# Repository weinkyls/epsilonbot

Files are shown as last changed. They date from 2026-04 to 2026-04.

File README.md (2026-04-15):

# The Delta Bot

### What is the Delta Bot?
The Delta Bot is an open-source DIY robot AI platform that uses Radxa's single board computer, the [Rock 5B](https://radxa.com/products/rock5/5b/), a simple [camera module](https://www.raspberrypi.com/products/camera-module-v2/), Parallax's [Continuous Rotation Servo Motors](https://www.parallax.com/product/parallax-continuous-rotation-servo-factory-centered/), and the [RPLIDAR A1](https://www.slamtec.com/en/lidar/a1), a LIDAR camera by Slamtec.

<p align="center">
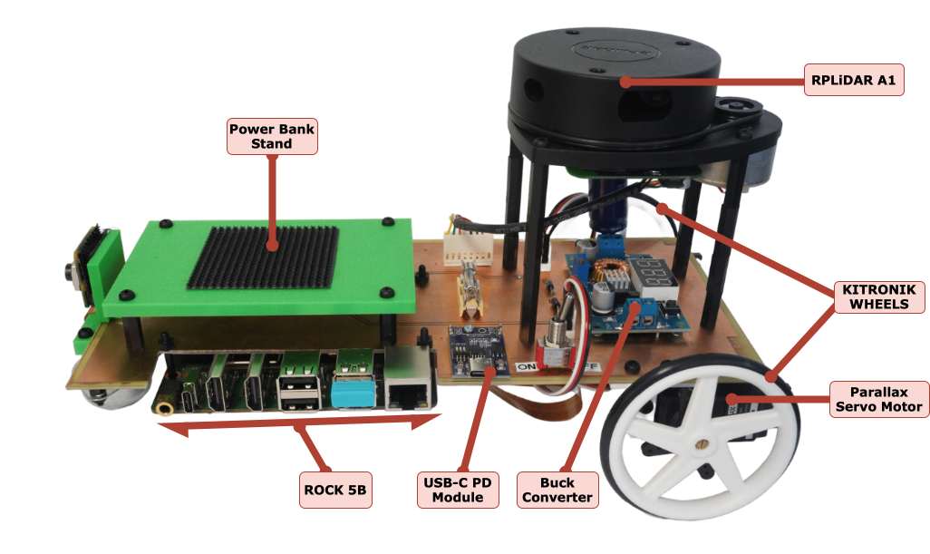
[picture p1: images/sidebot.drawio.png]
Side View
  
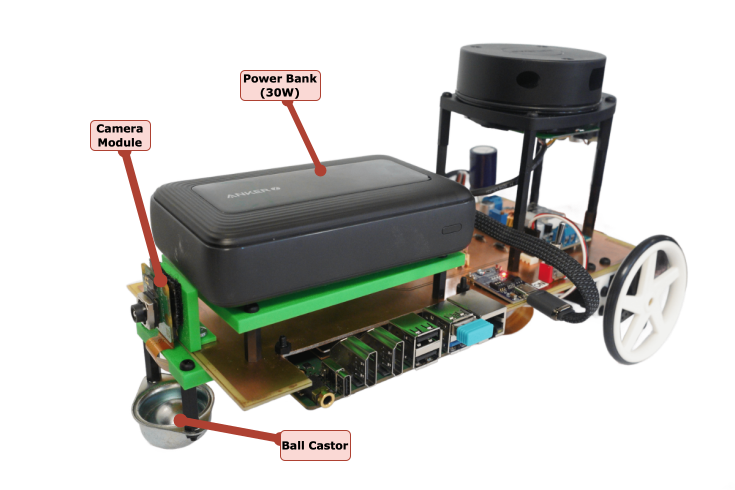
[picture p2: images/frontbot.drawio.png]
Front View
  
</p>

### Purpose & Vision

<p align="center">
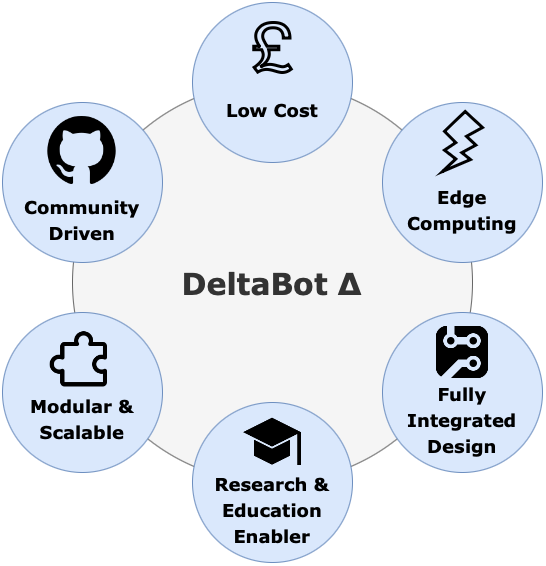
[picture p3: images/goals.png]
Goals
  
</p>

### What can it do?

- 360 Degree 2D LiDAR Scans
- Precise Servo Movement 
- 1080p Video Capture
- Can be configured for Line Following, SLAM, Obstacle Detection, and more!

### Additional Mechanical Parts
Additional Mechanical Parts were designed in CAD and can be accessed [here](additional_files/deltabot.f3z).
These were used to secure the external components onto the Single PCB Chassis:
<p align="center">
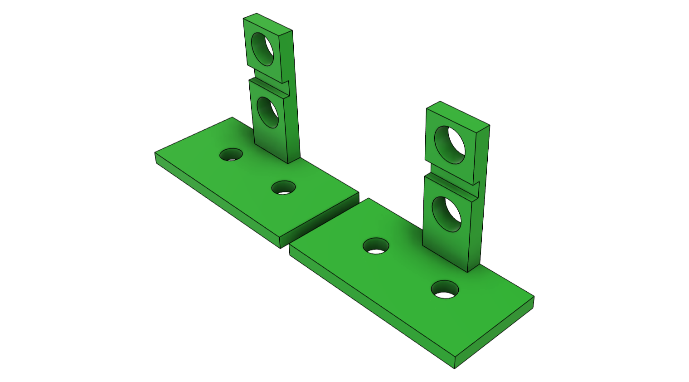
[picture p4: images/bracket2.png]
  
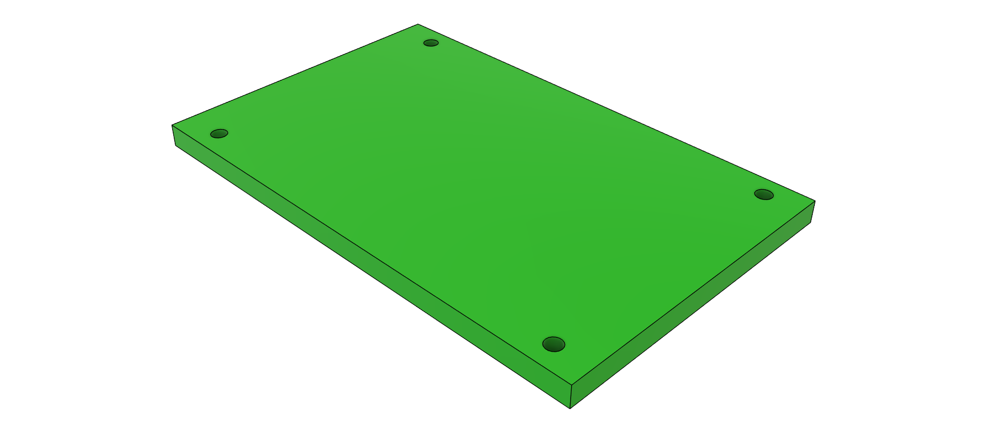
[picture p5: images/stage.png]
  
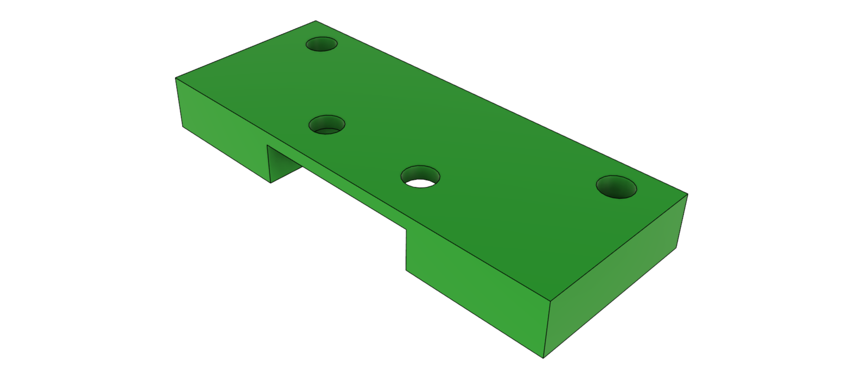
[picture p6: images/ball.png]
  
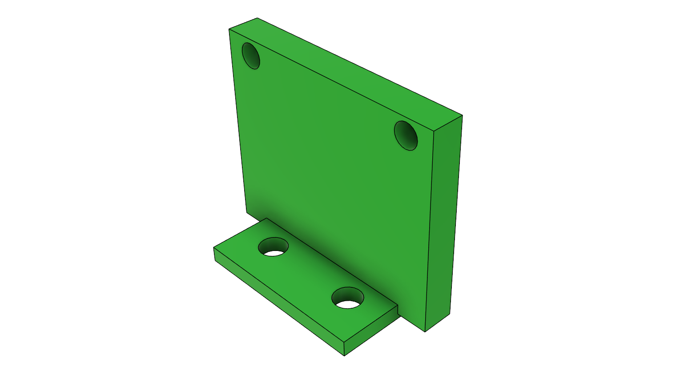
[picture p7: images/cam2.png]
  
</p>

## Credits
- Saleh AlMulla - 2721704A@student.gla.ac.uk
- Bernd Porr -  bernd.porr@glasgow.ac.uk

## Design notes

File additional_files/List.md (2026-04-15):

### Ordered:

- USB C PD - [CRGANGZY PD/QC/AFC Type-C Fast Charge Trigger Polling Detector PD2.0 PD3.0 To DC Fast Charge Trigger Board Voltage Output](https://www.amazon.co.uk/CRGANGZY-Trigger-Polling-Detector-Voltage/dp/B0DBJ388K9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) 
- DC-DC BUCK CONVERTER - [DollaTek Small DC Buck Voltage Converter Step Down Voltage Regulator Module Board 4-38V to 1.25-36V 5V/12V Adjustable Output Voltage Stabilizer Transformer](https://www.amazon.co.uk/dp/B07DK6WN63?ref=ppx_yo2ov_dt_b_fed_asin_title)
- M.2 NVME 256GB - [Silicon Power PCIe M.2 NVMe SSD 256GB Gen3x4 R/W up to 2, 100/1, 200MB/s Internal SSD](https://www.amazon.co.uk/dp/B07ZH6QR8Q?ref=ppx_yo2ov_dt_b_fed_asin_title&th=1)
- RADXA ROCK5B - [Radxa ROCK 5 Model B 8GB Single Board Computer, 249-3159 \(Board Computer\)](https://www.amazon.co.uk/Single-Computer-Rockchip-Cortex-A76-Rock/dp/B0BRL4PCG7/) 
- x2 Parallax Continuous Rotation Servo Motors - [900-00008 PARALLAX, SERVO- CONTINUOUS ROTATION-S3 SERVO](https://uk.farnell.com/parallax/900-00008/servo-continuous-rotation-s3-servo/dp/2819351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) 
- x2 Kitronic Wheels - [2593-SV KITRONIK, Wheel Kit, White, 5 Spoke, ABS, Rotation Servo Motors | Newark Electronics](https://www.newark.com/kitronik/2593-sv/wheels-white-rotation-servo-motor/dp/30AK0833)
- RPLIDAR A1 - [DFR0315 DFROBOT, Development Kit, 2D Laser Scanner, 360°, 5.5Hz, 12m range](https://uk.farnell.com/dfrobot/dfr0315/dev-kit-360-deg-laser-scanner/dp/3517894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)
- RPi Camera Module 3 - [Raspberry Pi Camera Module 3](https://thepihut.com/products/raspberry-pi-camera-module-3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)
- Anker Zolo PowerBank - [Anker Zolo Power Bank, 20,000mAh 30W](https://www.amazon.co.uk/dp/B0CZ9LH53B?ref=ppx_yo2ov_dt_b_fed_asin_title&th=1)

### 3D-Printed:
- x2 Servo Mounting Brackets
- Camera Mounting Bracket
- Castor Ball Mounting Bracket
- Power Bank Stage

### Standard Components:
- SPDT Toggle Switch
- F3.15L250V fuse
- x2 1N4007 Diodes
- Fuse Holder & 3A Fuse
- 40 pin 2x20 GPIO Stackable Header 2.54mm
- x2 1x3 Pin Header 2.54mm
- 1x7 Pin Header 2.54mm

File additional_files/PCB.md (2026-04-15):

# DeltaBot PCB Overview

The DeltaBot PCB was designed in **KiCad** with a double-sided layer layout. The design integrates key subsystems including the **Radxa ROCK 5B**, LiDAR sensor, camera module, and servo motors.

<p align="center">
  
</p>

---

## Power System
- Powered via **USB-C Power Delivery (PD)** module at **9V**, stepped down to **5V** using a **DC-DC buck converter**
- A **3.15A fuse** protects against overcurrent
- An **SPDT switch** provides manual ON/OFF control
- A **2200 µF capacitor** suppresses 5V rail ripple for improved voltage stability
- **1 uF** blocking capacitors between each POWER & GND

The following summarizes the power distribution architecture:

<p align="center">
  
</p>

_Note: Current draw listed is based on peak operational requirements._

---

## PCB Layout (Front & Back Layers)

<p align="center">
  
</p>
<p align="center">
  
</p>

---

## ROCK 5B GPIO Pin Assignments

| Function | GPIO Pin(s) | Description |
|---|---|---|
| +5V Power | 2, 4 | Supplies power to board |
| GND | Multiple | Ground reference |
| UART_TX | 8 | TX to LiDAR's RX |
| UART_RX | 10 | RX from LiDAR's TX |
| MOTO_CTRL | 18 | PWM for LiDAR motor |
| PWM_L | 32 | PWM control for left servo |
| PWM_R | 33 | PWM control for right servo |

To change or add to the layout, check [here](https://wiki.radxa.com/Rock5/hardware/5b/gpio) for the rock's gpio connections.

---

## Connectors

- **J2 (LiDAR)**: 7-pin Molex  
  - UART (TX/RX), PWM for motor control, 5V & 8.34V power lines
  - There is a useful image on the LiDAR wiring in the read.me of [this repository](https://github.com/berndporr/rplidar_rpi).
- **J3 / J4 (Servo Motors)**: 3-pin headers  
  - 5V, GND, PWM (Left/Right)

---

## Files

- [Full Schematic](schematic_files/DeltaBot.kicad_sch)
- [PCB Design](schematic_files/DeltaBot.kicad_pcb)
- [PCB Footprints](schematic_files/deltabot.pretty.zip)
- [Rock 5B KiCAD Symbol](schematic_files/deltabot.lib.kicad_sym)
  
---

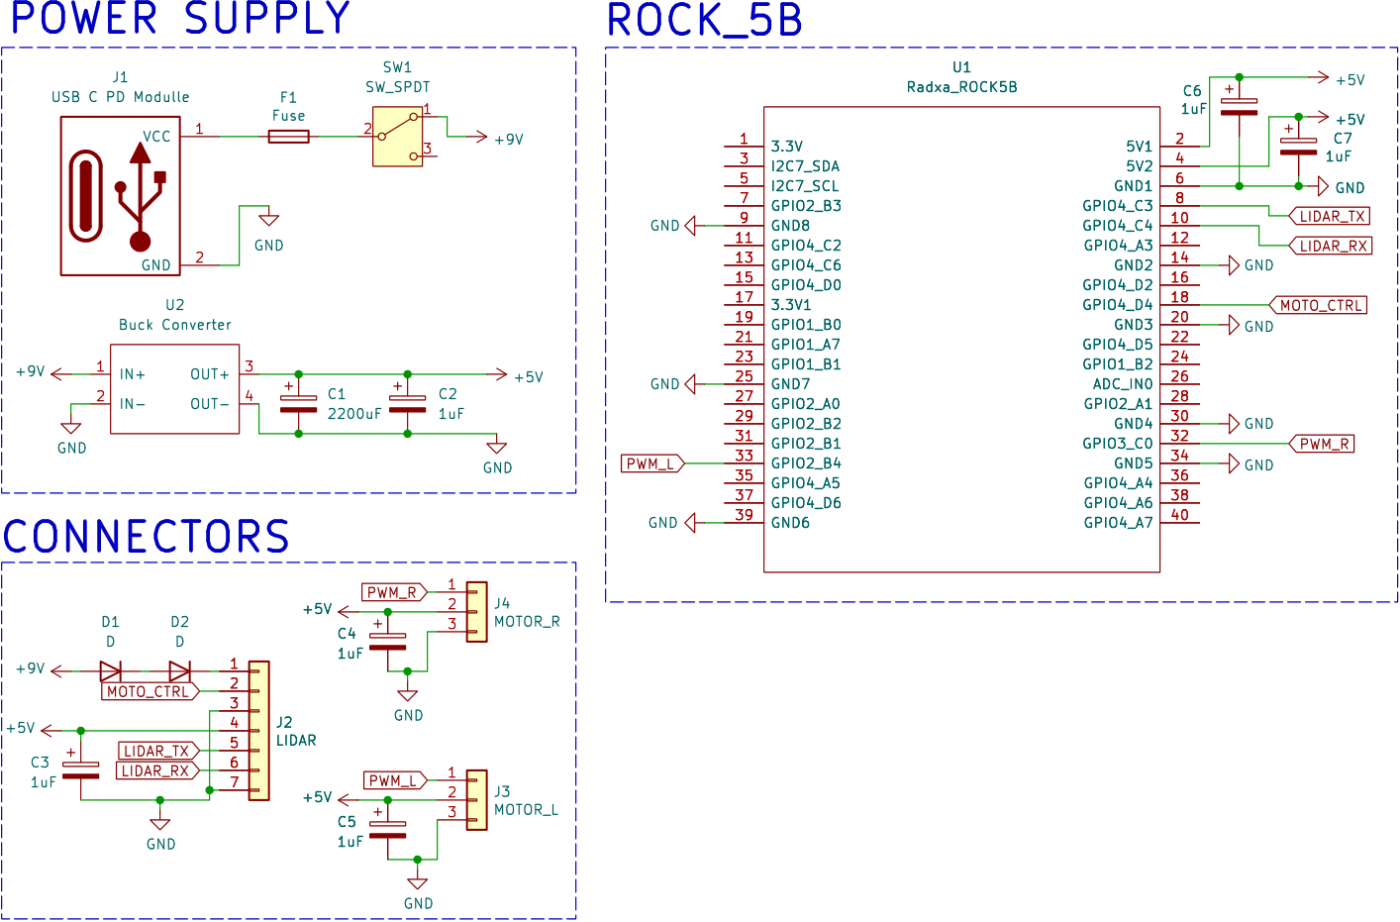
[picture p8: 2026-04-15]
images/schematic.png

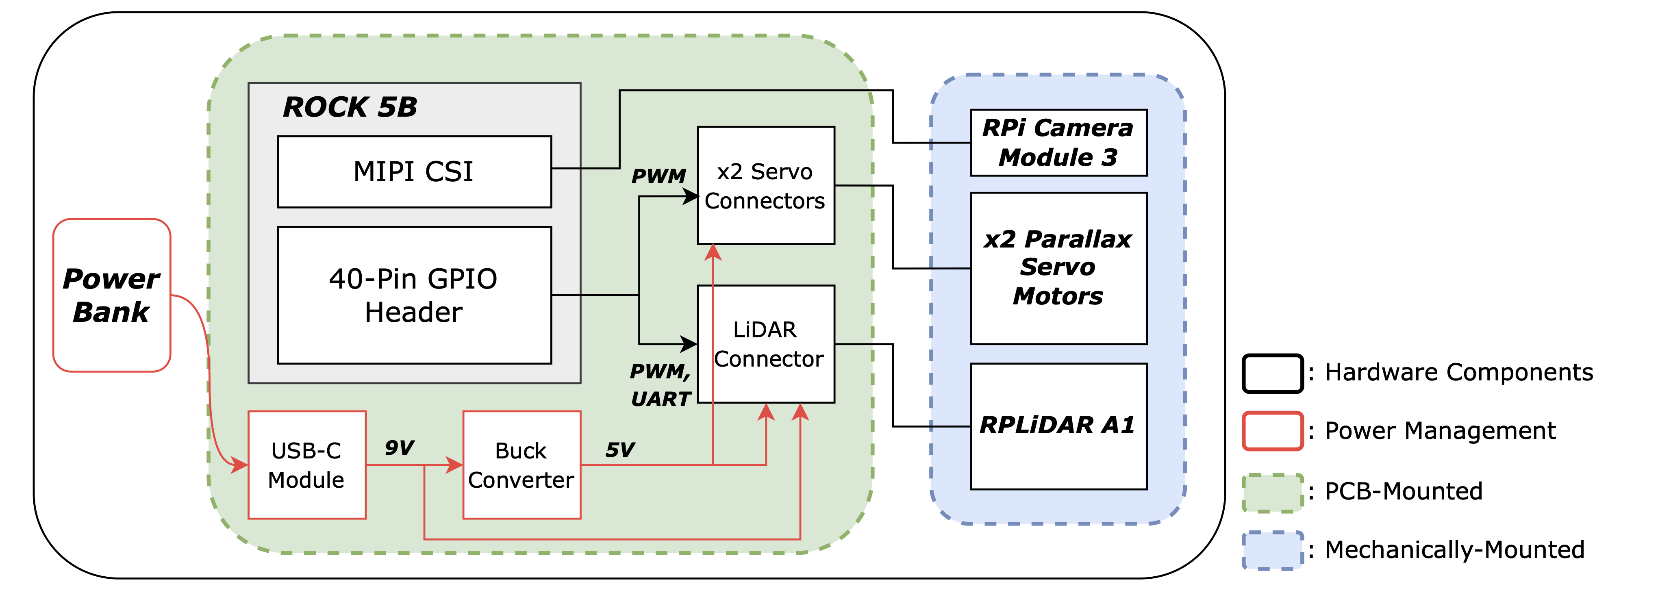
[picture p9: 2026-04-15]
images/Hardware_Architecture.png

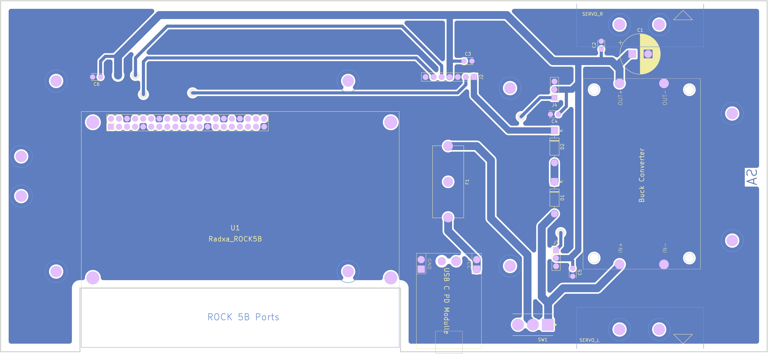
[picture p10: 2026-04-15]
images/DeltaBot-B_Cu.jpg

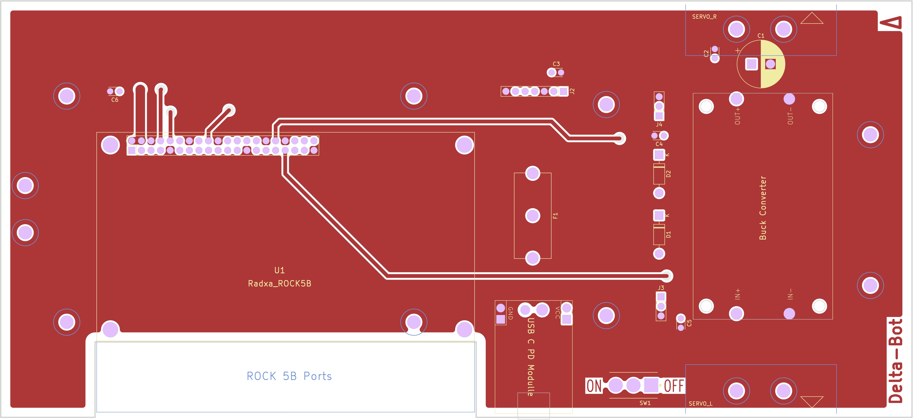
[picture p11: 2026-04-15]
images/DeltaBot-F_Cu.jpg

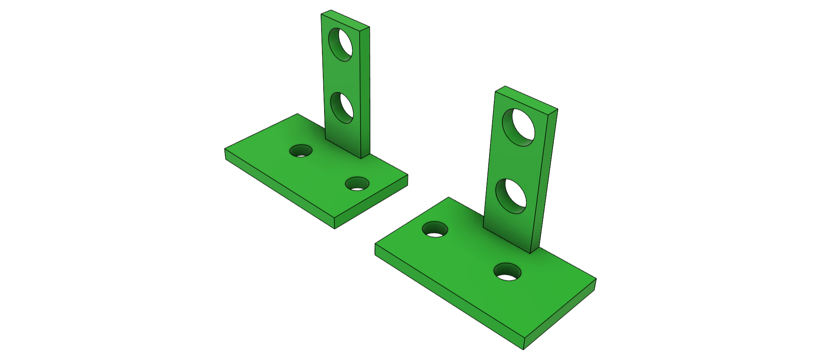
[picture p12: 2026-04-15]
images/bracket.png

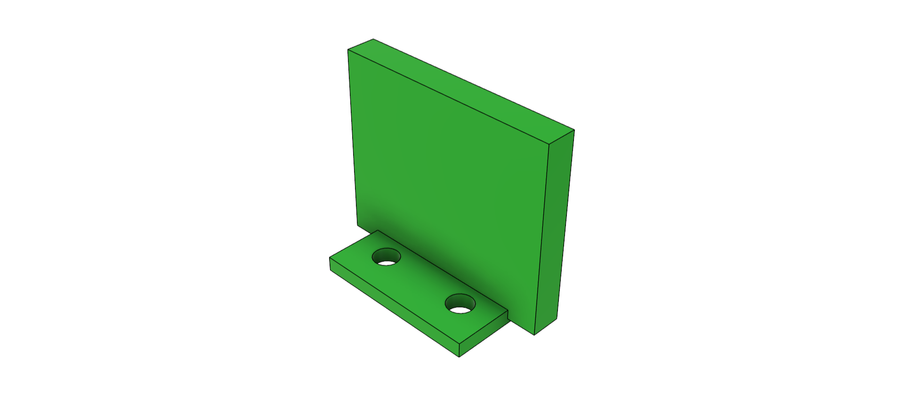
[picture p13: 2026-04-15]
images/cam.png

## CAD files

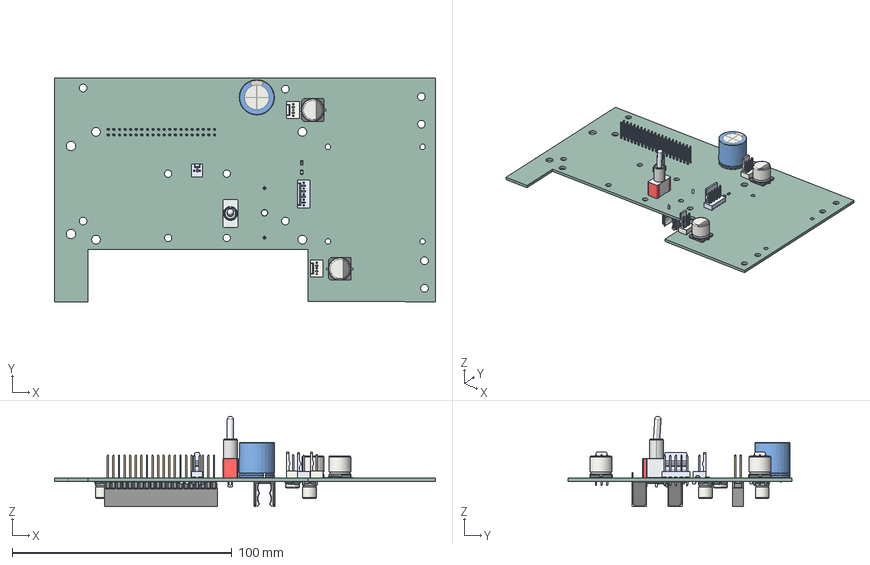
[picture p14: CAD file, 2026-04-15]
additional_files/schematic_files/epsilonbot/epsilonbot_PCB.step
173.2 x 101.8 x 41.1 mm
R_0805_2012Metric x 12
LED_0805_2012Metric
CP_Elec_10x10 x 2
Molex_KK-254_AE-6410-03A_1x03_P2.54mm_Vertical x 2
CP_Radial_D16.0mm_P7.50mm
C_0805_2012Metric x 9
CP_Elec_6.3x3
CP_Elec_6.3x7.7 x 2
Fuseholder_Cylinder-5x20mm_Schurter_0031_8201_Horizontal_Open
DeltaBot_PCB

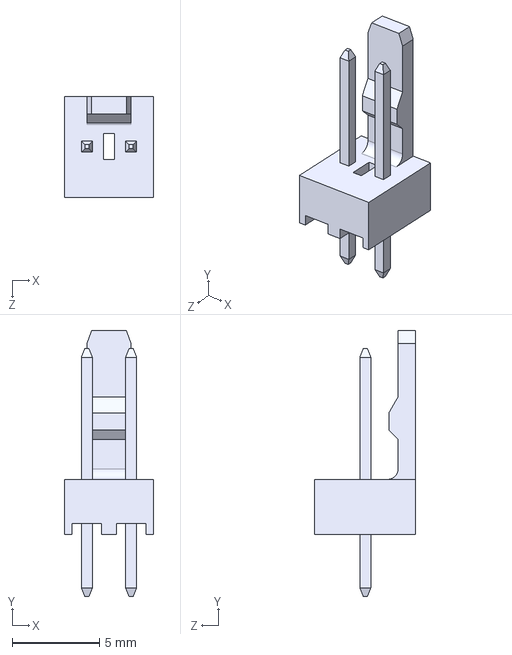
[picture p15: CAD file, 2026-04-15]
additional_files/schematic_files/epsilonbot/deltabot_3dmodels/1x2/139594.step
5.08 x 15.3 x 5.80 mm

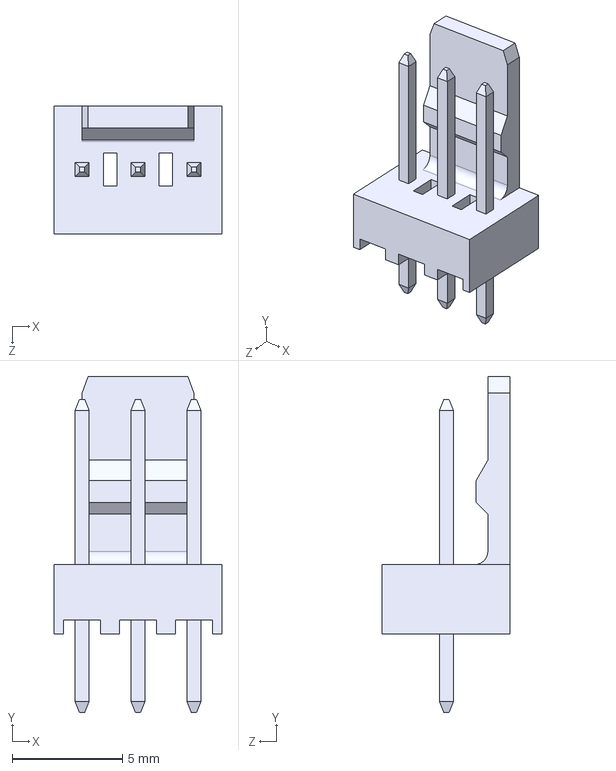
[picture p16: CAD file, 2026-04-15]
additional_files/schematic_files/epsilonbot/deltabot_3dmodels/1x3/139596.step
7.62 x 15.3 x 5.80 mm

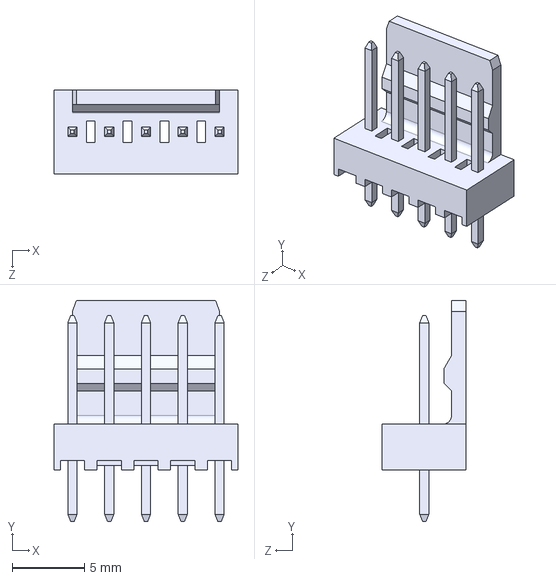
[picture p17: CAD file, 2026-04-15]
additional_files/schematic_files/epsilonbot/deltabot_3dmodels/1x5/139600.step
12.7 x 15.3 x 5.80 mm

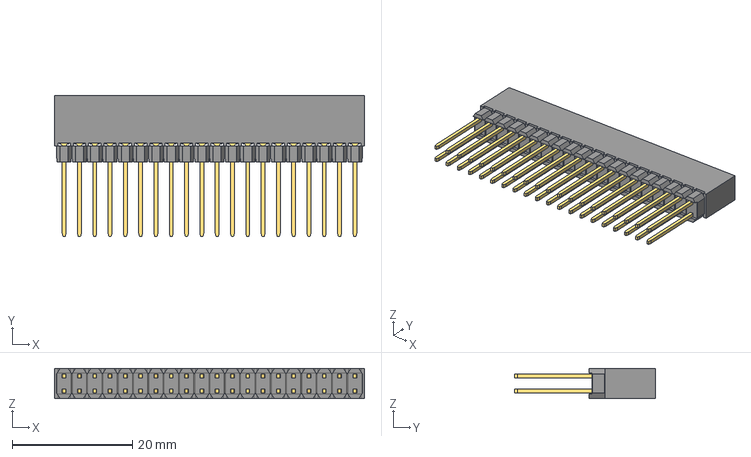
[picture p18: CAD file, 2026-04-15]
additional_files/schematic_files/epsilonbot/deltabot_3dmodels/2x20/6816794.stp
51.5 x 23.4 x 5.00 mm

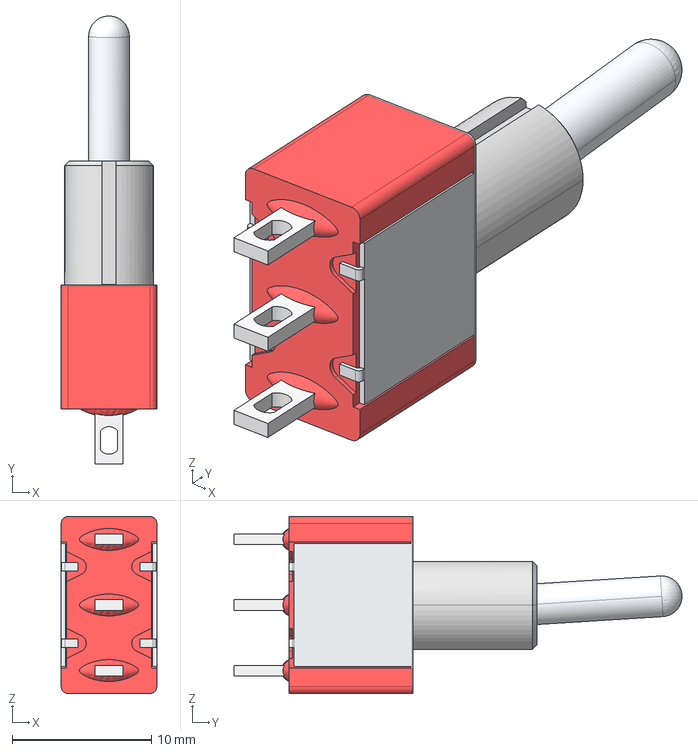
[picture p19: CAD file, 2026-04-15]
additional_files/schematic_files/epsilonbot/deltabot_3dmodels/switch/7347062.stp
6.86 x 32.1 x 12.7 mm

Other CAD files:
additional_files/deltabot.f3z

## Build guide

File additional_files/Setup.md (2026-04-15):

# Getting Started:

### Items Needed (Requirements):
- Main computer: [RADXA ROCK5B](https://radxa.com/products/rock5/5b/#documentation)
- NVME SSD (any size)
- MicroSD card (any size)
- USB Mouse & Keyboard
- Ethernet Cable & Connection
- HDMI Cable & Display
- USB-C cable with ≥30W Power Adapter

## Installing the System:
Refer to [RADXA official 'Getting Started' Page](https://docs.radxa.com/en/rock5/rock5b/getting-started).

Image Downloads: [Summary of resource downloads](https://docs.radxa.com/en/rock5/rock5b/download).

### In short, 
- Use a MicroSD card as a boot disk to flash the system’s SPI.
  - Download & Open [balenaEtcher](https://etcher.balena.io/#download-etcher) to burn the specific image you want to use (in this case Debian was used).
- Boot up your device and login - User: radxa | Password: radxa
- Copy the Image file from the MicroSD card into the NVME. Refer to [this page](https://docs.radxa.com/en/rock5/rock5b/getting-started/install-os/nvme).

If done successfully, power off the system, remove the MicroSD card, and the system should boot from the NVME drive.

### Troubleshooting tips:
- Run `lsblk` in the command line, and it should output something like this if steps were done correctly:
```
NAME        MAJ:MIN RM   SIZE RO TYPE MOUNTPOINT
mtdblock0    31:0    0    16M  0 disk 
zram0       254:0    0   3.9G  0 disk [SWAP]
nvme0n1     259:0    0 238.5G  0 disk 
├─nvme0n1p1 259:1    0    16M  0 part /config
├─nvme0n1p2 259:2    0   300M  0 part /boot/efi
└─nvme0n1p3 259:3    0 238.2G  0 part /
```
  - Names `mmcblkXpY` are for SD card partitions | `nvmeXbYpZ` for NVME SSD partitions.
  - The device with `/boot/efi` under the MOUNTPOINT column is your root filesystem and boot device.

- Make sure to use the correct path when copying the system image onto the NVME and replace `radxa@192.167.2.66` with the correct username and IP address for you ROCK 5B board.
  - You can find your IP address of your board by running `ip addr show` on the command line.
    - This will display the network interfaces and their IP addresses. Look `inet` followed by an address like `192.167.x.x` or `127.x.x.x`.

## Configure the PWM pins:

The ROCK5B exposes multiple PWM-capable pins. First enable the PWM controller and channel via the sysfs interface.

### Step 1: Activate Pins Using `r-setup`

[`r-setup`]([https://github.com/radxa/rsetup](https://docs.radxa.com/en/rock5/rock5c/radxa-os/rsetup)) is a utility by Radxa to simplify GPIO, I2C, SPI, and PWM configuration. Use it to configure pins to their correct function.

### Step 2: Export & Set PWM

export the correct PWM channel using sysfs. For PWM5_M2, it is pwmchip5, channel 0:

`echo 0 | sudo tee /sys/class/pwm/pwmchip5/export`

`ls /sys/class/pwm/pwmchipX/pwmY` to list activated pins and check if export worked.

pwmchipX → The PWM controller (varies based on hardware)
pwmY → The PWM channel within that controller

Let's use Pin 18, ie. PWM5_M2 for example:

`echo 0 | tee /sys/class/pwm/pwmchip5/export`

You can manually set the PWM signal by

```
echo 20000000 | tee /sys/class/pwm/pwmchip5/pwm0/period
echo 1500000 | tee /sys/class/pwm/pwmchip5/pwm0/duty_cycle
echo 1 | tee /sys/class/pwm/pwmchip5/pwm0/enable
```

#### Note:
Parallax Continuous Rotation Servo Motors require a pulse range of 1.3-1.5ns and a 20ms pause between every pulse:
- A pulse duration of 1.5 ms corresponds to a neutral position.
- A pulse duration below 1.5 ms induces clockwise rotation.
- A pulse duration above 1.5 ms, induces counterclockwise rotation.

### Step 3: C++ Integration
All the code scripts are found in [scripts](scripts).
Including the Servo [test script](scripts/pwm_test.cpp).

## Setting up the LIDAR (pending full integration)

1. **Connect the RPLIDAR A1** to the ROCK5B using UART on `/dev/ttyS2`:
   - TX from the LIDAR → GPIO10 (RX on ROCK5B)
   - RX from the LIDAR → GPIO8 (TX on ROCK5B)

2. Configure pins:
   - Use rsetup to turn on the UART2_M2 and PWM_5 on the ROCK 5B

3. Configure pins:
   - Build the [rplidar_rock](scripts/rplidar_rock).
```
mkdir build && cd build
cmake ..
make -j$(nproc)
```
4. Run the demo:
  - Test LIDAR startup and initialization by running `./printdata`

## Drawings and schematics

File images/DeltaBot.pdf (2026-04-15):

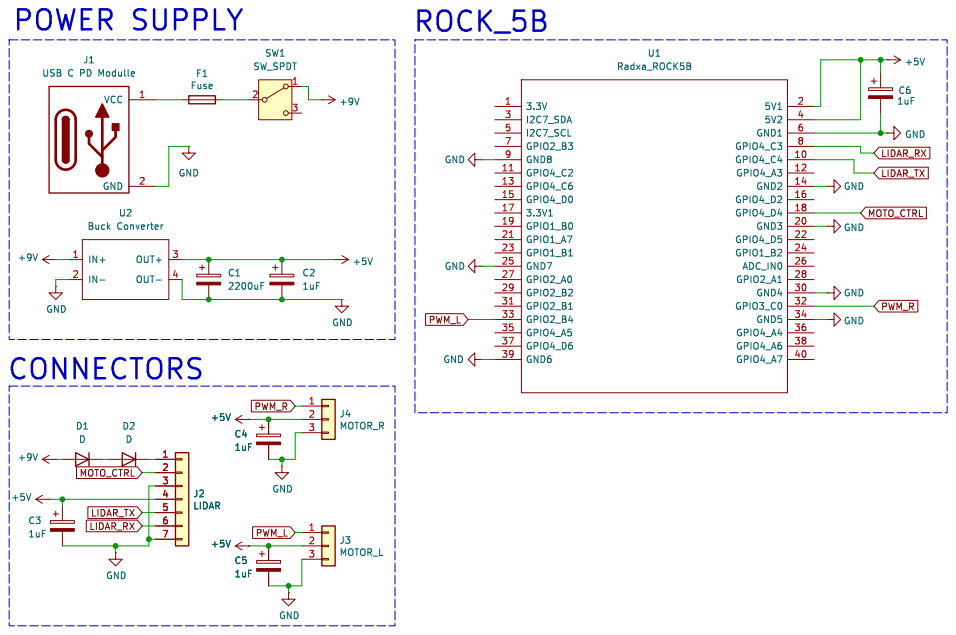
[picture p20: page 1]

LIDAR_TX POWER SUPPLY
J1 USB C PD Modulle +9V GND MOTO_CTRL

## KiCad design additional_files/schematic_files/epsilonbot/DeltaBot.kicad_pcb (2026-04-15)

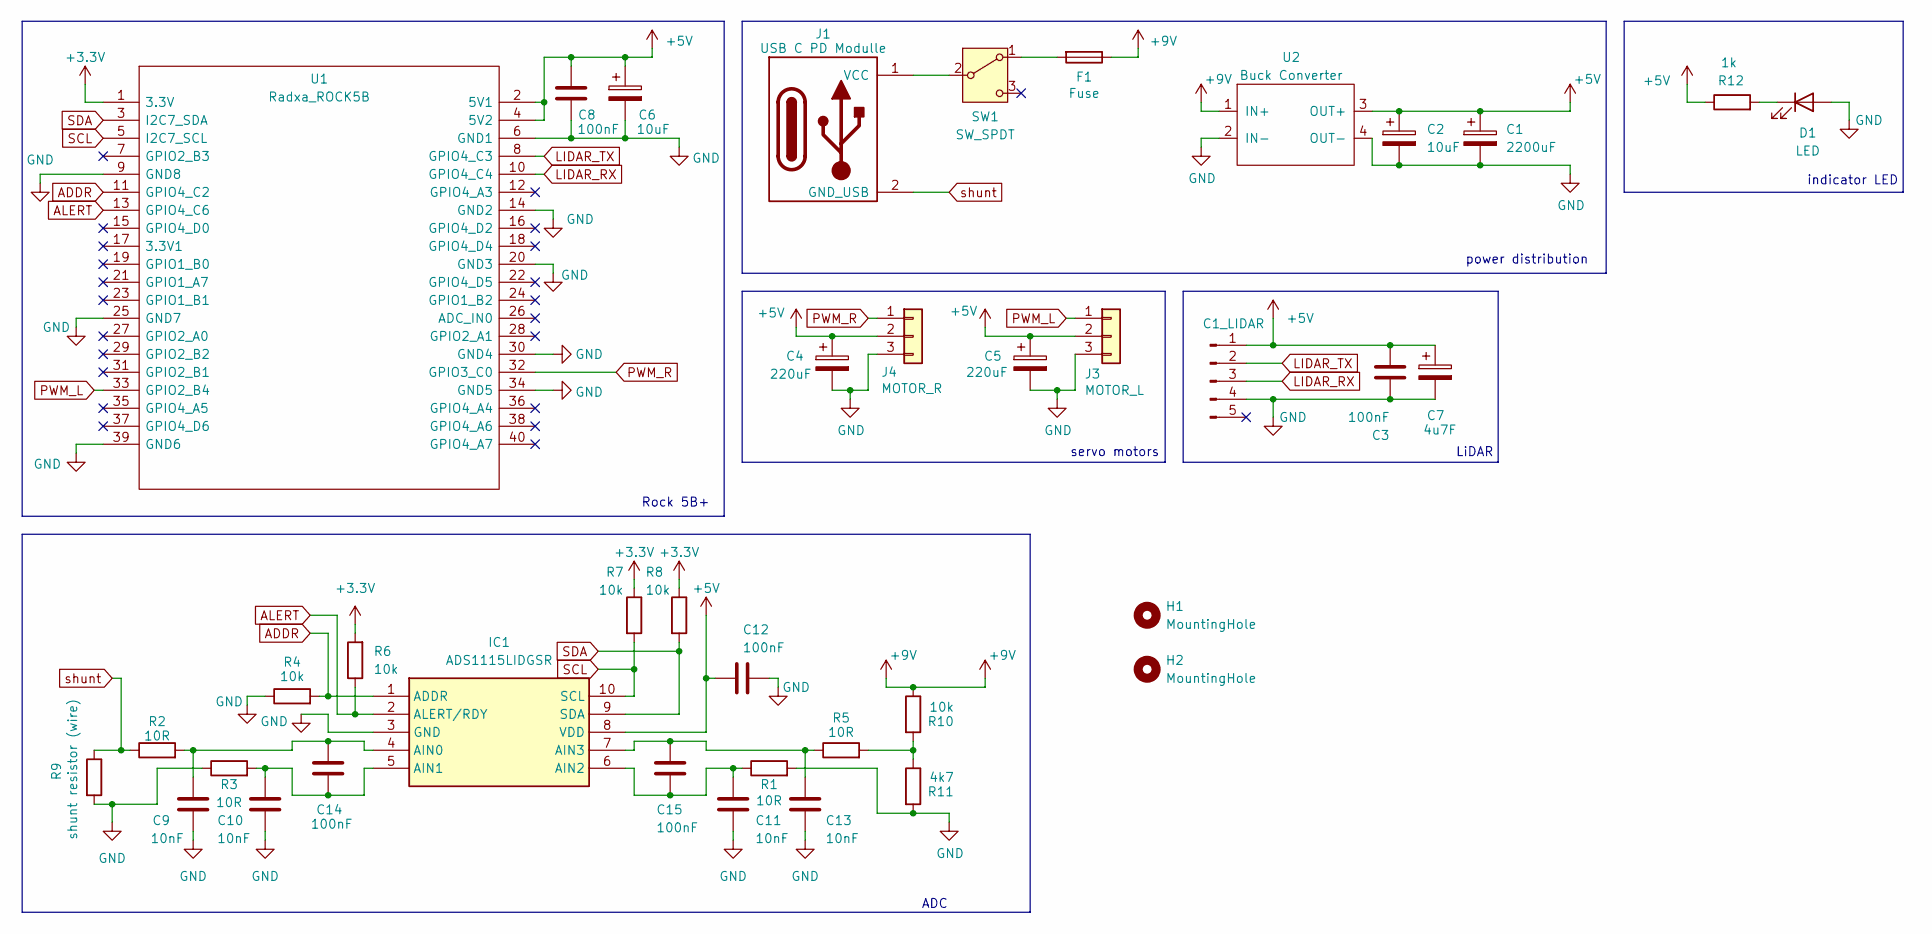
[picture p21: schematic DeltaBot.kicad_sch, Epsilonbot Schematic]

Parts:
C1: 2200uF; CP_Radial_D16.0mm_P7.50mm
C2: 10uF; CP_Elec_6.3x3
C3, C8, C12, C14, C15: 100nF; C_0805_2012Metric_Pad1.18x1.45mm_HandSolder
C4, C5: 220uF; CP_Elec_10x10
C6: 10uF; CP_Elec_6.3x7.7
C7: 4u7F; CP_Elec_6.3x7.7
C9, C10, C11, C13: 10nF; C_0805_2012Metric_Pad1.18x1.45mm_HandSolder
D1: LED; LED_0805_2012Metric_Pad1.15x1.40mm_HandSolder
F1: Fuse; Fuseholder_Cylinder-5x20mm_Schurter_0031_8201_Horizontal_Op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
H1, H2: MountingHole; MountingHole_4.3mm_M4
IC1: ADS1115LIDGSR; SOP50P490X110-10N; Mouser Part Number 595-ADS1115LIDGSR
J1: USB C PD Modulle; USB_PD
J3: MOTOR_L; PinHeader_1x03_P2.54mm_Vertical
J4: MOTOR_R; PinHeader_1x03_P2.54mm_Vertical
J5: C1_LIDAR; C1 LiDAR
R1, R2, R3, R5: 10R; R_0805_2012Metric_Pad1.20x1.40mm_HandSolder
R4, R6, R7, R8, R10: 10k; R_0805_2012Metric_Pad1.20x1.40mm_HandSolder
R9: shunt resistor (wire); R_0805_2012Metric_Pad1.20x1.40mm_HandSolder
R11: 4k7; R_0805_2012Metric_Pad1.20x1.40mm_HandSolder
R12: 1k; R_0805_2012Metric_Pad1.20x1.40mm_HandSolder
SW1: SW_SPDT; TE_4-1825136-5
U1: Radxa_ROCK5B; ROCK_5B; Manufacturer_Part_Number ROCK5B V1.3
U2: Buck Converter; BUCK_CONV

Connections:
+3.3V: R6.2, R7.1, R8.1, U1.1 (3.3V)
+5V: C1.1, C2.1, C3.1, C4.1, C5.1, C6.1, C7.1, C8.1, C12.2, IC1.8 (VDD), J3.2, J4.2, J5.1 (VCC), R12.1, U1.2 (5V1), U1.4 (5V2), U2.3 (OUT+)
+9V: F1.1, R10.1, U2.1 (IN+)
ADDR: IC1.1 (ADDR), R4.2, U1.11 (GPIO4_C2)
ALERT: IC1.2 (ALERT/RDY), R6.1, U1.13 (GPIO4_C6)
GND: C1.2, C2.2, C3.2, C4.2, C5.2, C6.2, C7.2, C8.2, C9.2, C10.2, C11.2, C12.1, C13.2, D1.2 (A), IC1.3 (GND), J3.3, J4.3, J5.4 (GND), R1.2, R3.1, R4.1, R9.2, R11.2, U1.6 (GND1), U1.9 (GND8), U1.14 (GND2), U1.20 (GND3), U1.25 (GND7), U1.30 (GND4), U1.34 (GND5), U1.39 (GND6), U2.2 (IN-), U2.4 (OUT-)
LIDAR_RX: J5.3 (RX), U1.10 (GPIO4_C4)
LIDAR_TX: J5.2 (TX), U1.8 (GPIO4_C3)
unnamed: D1.1 (K), R12.2
unnamed: C9.1, C14.1, IC1.4 (AIN0), R2.2
unnamed: C10.1, C14.2, IC1.5 (AIN1), R3.2
unnamed: C11.1, C15.2, IC1.6 (AIN2), R1.1
unnamed: C13.1, C15.1, IC1.7 (AIN3), R5.1
unnamed: J1.1 (VCC), SW1.2 (B)
unnamed: R5.2, R10.2, R11.1
unnamed: F1.2, SW1.1 (A)
PWM_L: J3.1, U1.33 (GPIO2_B4)
PWM_R: J4.1, U1.32 (GPIO3_C0)
SCL: IC1.10 (SCL), R7.2, U1.5 (I2C7_SCL)
SDA: IC1.9 (SDA), R8.2, U1.3 (I2C7_SDA)
shunt: J1.2 (GND_USB), R2.1, R9.1

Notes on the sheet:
ADC
servo motors
Rock 5B+
LiDAR
indicator LED
power distribution

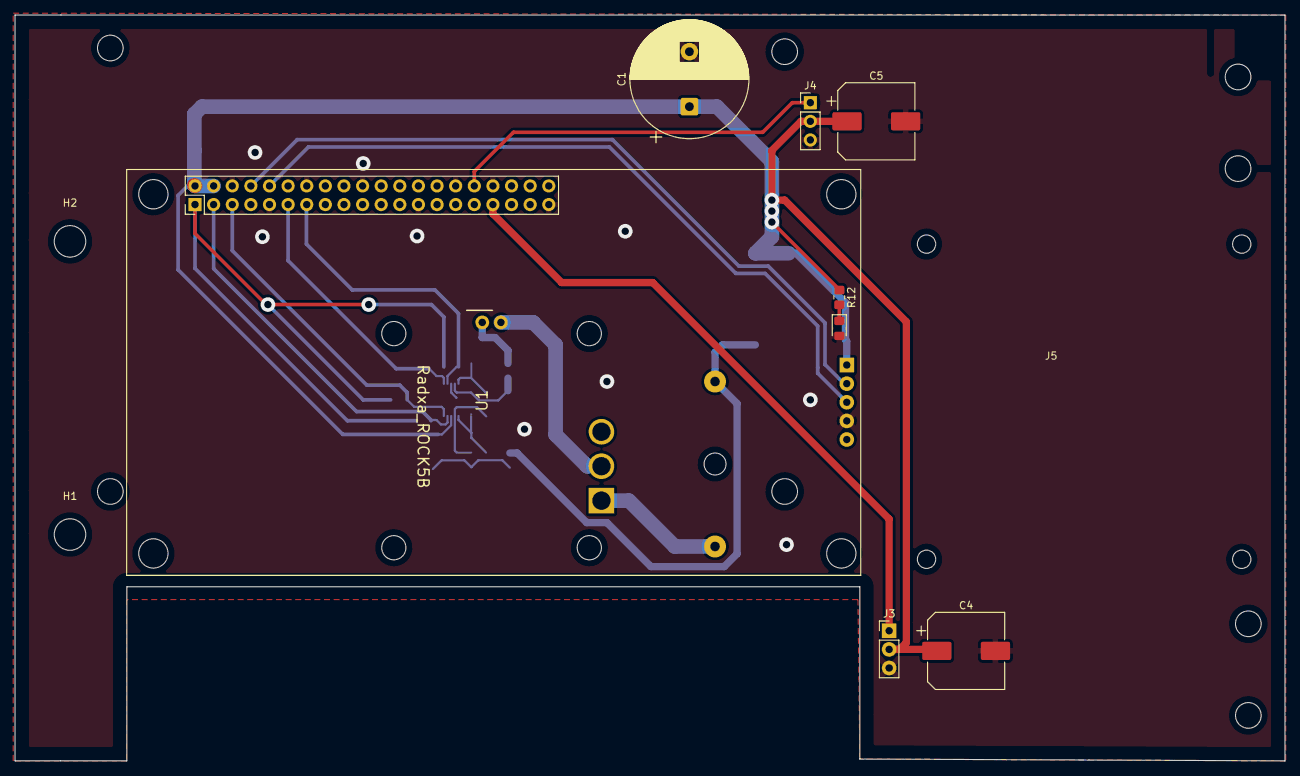
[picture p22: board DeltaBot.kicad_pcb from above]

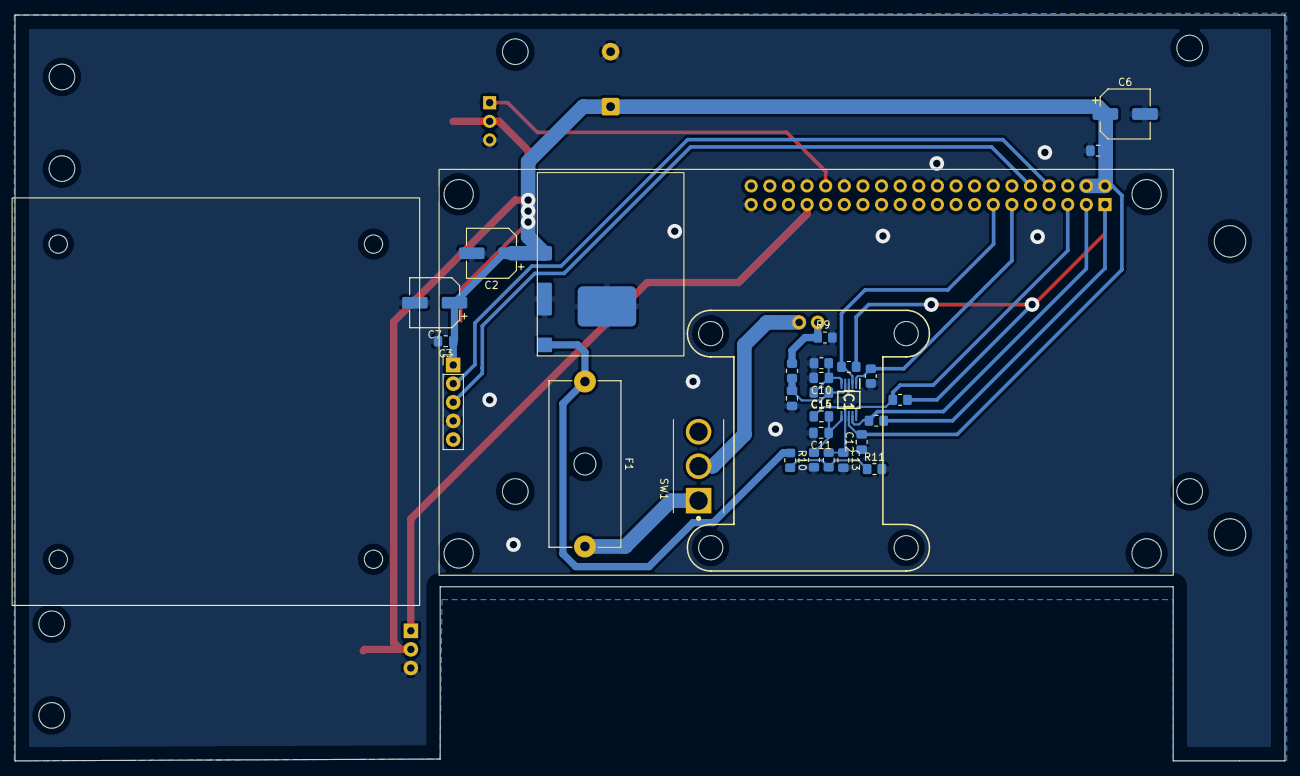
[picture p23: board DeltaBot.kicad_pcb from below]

Board: 2 copper layers, 173.2 x 101.8 mm, 39 parts (29 on the bottom side), 21 nets.

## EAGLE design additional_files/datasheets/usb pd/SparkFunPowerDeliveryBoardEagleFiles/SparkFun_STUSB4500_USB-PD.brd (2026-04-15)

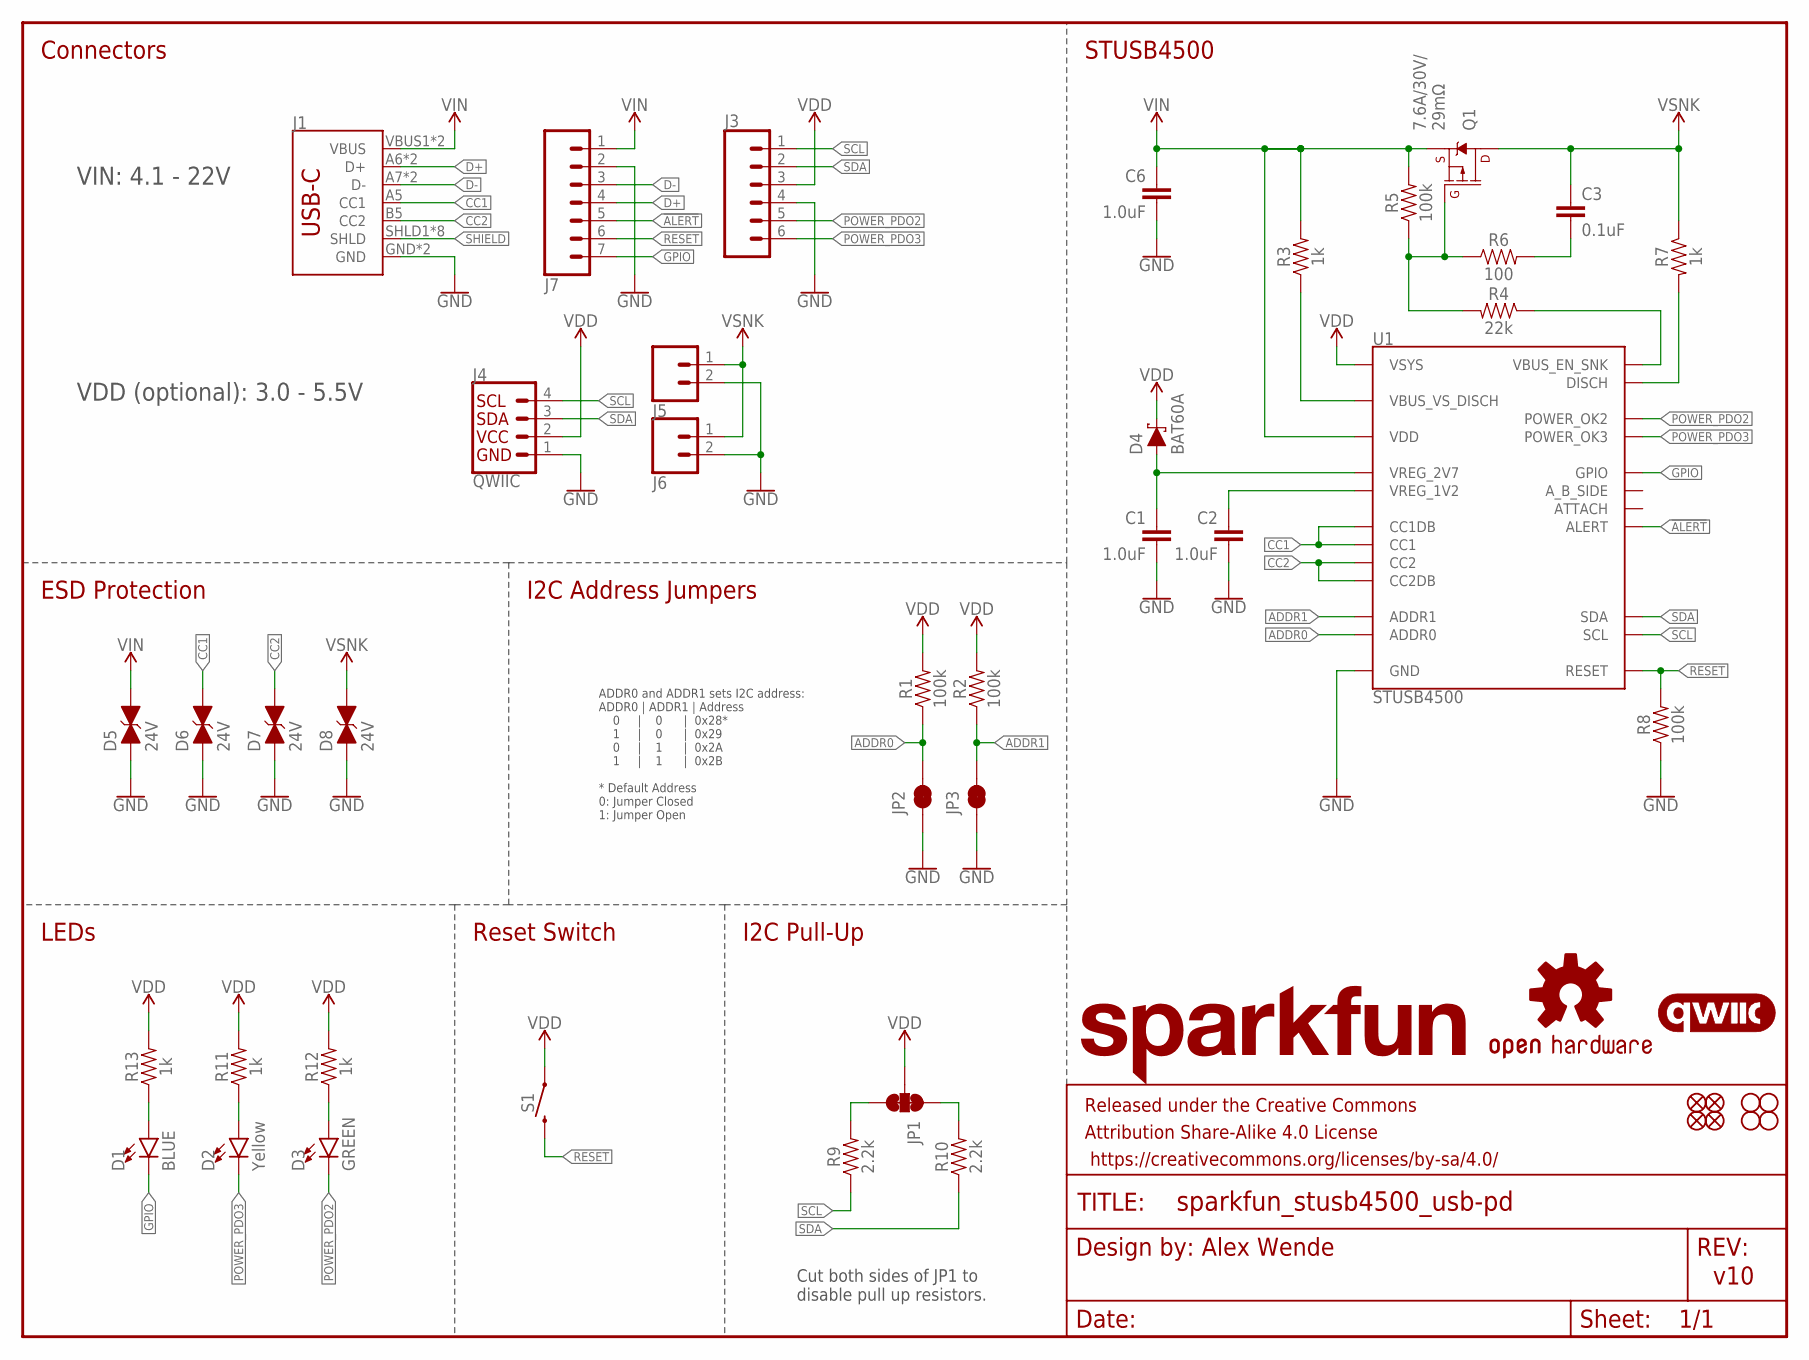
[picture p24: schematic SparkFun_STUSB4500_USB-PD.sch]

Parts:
C1, C2, C6: 1.0uF; 0603
C3: 0.1uF; 0603
D1: BLUE; LED-0603
D2: Yellow; LED-0603
D3: GREEN; LED-0603
D4: BAT60A; SOD-323
D5, D6, D7, D8: 24V; 0603
FD1, FD2, FD3, FD4: FIDUCIALUFIDUCIAL; FIDUCIAL-MICRO
FRAME1: FRAME-LETTER; CREATIVE_COMMONS
H1, H2, H3, H4: STAND-OFF
J1: USB_C2-LAYER; USB-C-16P
J3: CONN_06NO_SILK_NO_POP; 1X06_NO_SILK
J4: QWIIC; JST04_1MM_RA
J5: CONN_023.5MM; SCREWTERMINAL-3.5MM-2
J6: CONN_021X02_NO_SILK; 1X02_NO_SILK
J7: CONN_07NO_SILK; 1X07_NO_SILK
JP1: JUMPER-SMT_3_2-NC_TRACE_NO-SILK; SMT-JUMPER_3_2-NC_TRACE_NO-SILK
JP2, JP3: JUMPER-SMT_2_NC_TRACE_NO-SILK; SMT-JUMPER_2_NC_TRACE_NO-SILK
LOGO1: OSHW-LOGOS; OSHW-LOGO-S
LOGO2: SFE_LOGO_NAME.1_INCH; SFE_LOGO_NAME_.1
LOGO3: QWIIC_LOGO_5MM; QWIIC_5MM
Q1: 9A/30V/15mΩ; 8-POWERVDFN-3X3
R1, R2, R5, R8: 100k; 0603
R3, R7, R11, R12, R13: 1k; 0603
R4: 22k; 0603
R6: 100; 0603
R9, R10: 2.2k; 0603
S1: MOMENTARY-SWITCH-SPST-SMD-4.6X2.8MM; TACTILE_SWITCH_SMD_4.6X2.8MM
U1: STUSB4500; QFN-24

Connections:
1.2V: C2.1, U1.P$21 (VREG_1V2)
2.7V: C1.1, D4.A, U1.P$23 (VREG_2V7)
!ALERT: J7.5, U1.P$19 (ALERT)
ADDR0: JP2.2, R1.1, U1.P$12 (ADDR0)
ADDR1: JP3.2, R2.1, U1.P$13 (ADDR1)
CC1: D6.2 (C), J1.A5 (CC1), U1.P$1 (CC1DB), U1.P$2 (CC1)
CC2: D7.2 (C), J1.B5 (CC2), U1.P$4 (CC2), U1.P$5 (CC2DB)
D+: J1.A6 (D+), J1.B6 (D+), J7.4
D-: J1.A7 (D-), J1.B7 (D-), J7.3
DISCH: R7.2, U1.P$9 (DISCH)
EN_SNK: R4.1, U1.P$16 (VBUS_EN_SNK)
GND: C1.2, C2.2, C6.2, D5.1 (A), D6.1 (A), D7.1 (A), D8.1 (A), J1.GND, J1.GND2 (GND), J3.4, J4.1, J5.2, J6.2, J7.2, JP2.1, JP3.1, R8.1, U1.P$10 (GND), U1.P$25 (GND)
GPIO: D1.C, J7.7, U1.P$15 (GPIO)
unnamed: D2.A, R11.1
unnamed: D3.A, R12.1
unnamed: JP1.3, R9.2
unnamed: JP1.1, R10.2
unnamed: Q1.4 (G), R4.2, R5.1, R6.1
unnamed: C3.2, R6.2
unnamed: D1.A, R13.1
POWER_PDO2: D3.C, J3.5, U1.P$20 (POWER_OK2)
POWER_PDO3: D2.C, J3.6, U1.P$14 (POWER_OK3)
RESET: J7.6, R8.2, S1.3 (2), S1.4 (2), U1.P$6 (RESET)
SCL: J3.1, J4.4, R9.1, U1.P$7 (SCL)
SDA: J3.2, J4.3, R10.1, U1.P$8 (SDA)
SHIELD: J1.SHLD1 (SHLD), J1.SHLD2 (SHLD), J1.SHLD3 (SHLD), J1.SHLD4 (SHLD), J1.SHLD5 (SHLD), J1.SHLD6 (SHLD), J1.SHLD7 (SHLD), J1.SHLD8 (SHLD)
VBUS_VS_DISCH: R3.1, U1.P$18 (VBUS_VS_DISCH)
VDD: D4.C, J3.3, J4.2, JP1.2, R1.2, R2.2, R11.2, R12.2, R13.2, S1.1, S1.2 (1), U1.P$22 (VSYS)
VIN: C6.1, D5.2 (C), J1.VBUS1 (VBUS), J1.VBUS2 (VBUS), J7.1, Q1.1 (S), Q1.2 (S), Q1.3 (S), R3.2, R5.2, U1.P$24 (VDD)
VSNK: C3.1, D8.2 (C), J5.1, J6.1, Q1.5@1 (D), Q1.5@2 (D), Q1.5@3 (D), R7.1

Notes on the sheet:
ADDR0 and ADDR1 sets I2C address: ADDR0 | ADDR1 | Address 0 | 0 | 0x28* 1 | 0 | 0x29 0 | 1 | 0x2A 1 | 1 | 0x2B * Default Address 0: Jumper Closed 1: Jumper Open
Alex Wende
v10
STUSB4500
Connectors
I2C Pull-Up
LEDs
Reset Switch
I2C Address Jumpers
VIN: 4.1 - 22V
7.6A/30V/ 29mΩ
ESD Protection
VDD (optional): 3.0 - 5.5V
Cut both sides of JP1 to disable pull up resistors.

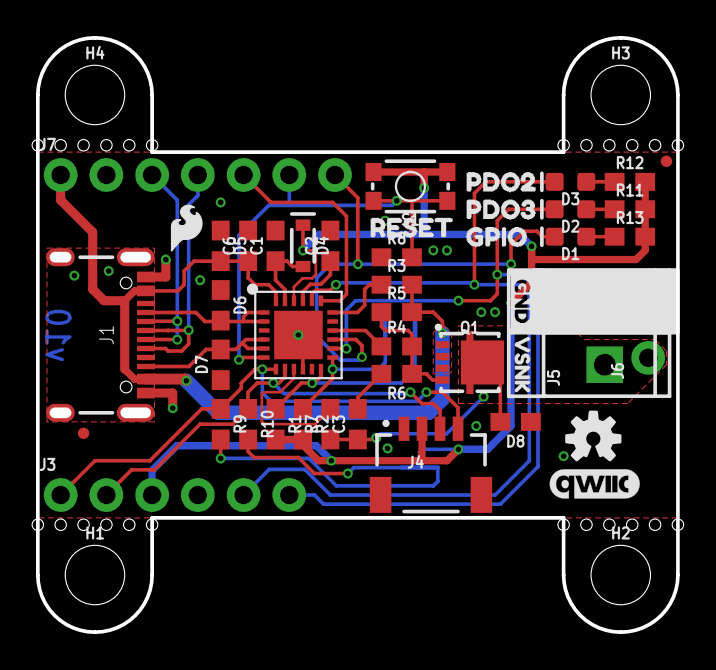
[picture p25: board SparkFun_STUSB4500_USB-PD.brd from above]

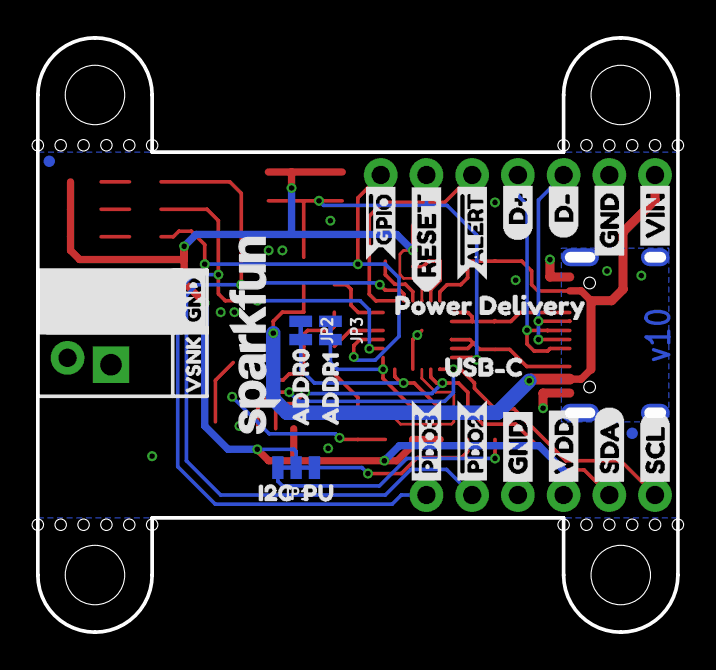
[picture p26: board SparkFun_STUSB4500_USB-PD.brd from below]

Board: 2 copper layers, 35.6 x 33.0 mm, 77 parts (27 on the bottom side), 30 nets.

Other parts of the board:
U$1: VDD2
U$2, U$11: GND6
U$3: SDA11
U$4: SCL12
U$5: #GPIO0
U$7: D#8
U$8: D#7
U$9: USB#C1
U$10: RESET10
U$12: VIN6
U$13: I2C2
U$14: PU3
U$15: ADDR00
U$16: ADDR11
U$17: RESET7
U$18: GPIO1
U$19: PDO24
U$20: PDO35
U$21, U$24: VSNK1
U$22, U$23: GND0
U$25: SFE_LOGO_FLAME_.1
U$26: #ALERT0
U$27: _POWER_DELIVERY2
U$29: #PDO20
U$30: #PDO31

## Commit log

2026-04-15 initial commit, detatching fork
    [139594.step, 139596.step, 139600.step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]
2026-04-20 removing old files
    [SparkFun_STUSB4500_USB-PD.brd, SparkFun_STUSB4500_USB-PD.sch]

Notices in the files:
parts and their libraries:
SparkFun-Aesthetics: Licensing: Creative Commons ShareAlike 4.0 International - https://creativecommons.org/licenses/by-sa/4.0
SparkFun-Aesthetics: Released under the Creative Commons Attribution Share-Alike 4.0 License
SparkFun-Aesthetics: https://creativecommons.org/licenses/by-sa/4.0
